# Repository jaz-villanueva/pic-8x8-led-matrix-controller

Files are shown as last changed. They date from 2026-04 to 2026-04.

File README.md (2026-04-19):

# PIC Ping Pong Game (8x8 LED Matrix)

## Overview
This project implements a two-player ping pong game using a PIC16F877A microcontroller and an 8x8 LED matrix driven by the MAX7219. The system displays the ball and paddles on the matrix, with button inputs controlling paddle movement.

The focus of this implementation is the **physical hardware realization**, including PCB assembly, soldering, and validation of a working embedded system.

---

## My Contribution
- Performed full hardware assembly and soldering of the PCB implementation
- Translated schematic and design into a working physical circuit
- Verified system operation through testing and debugging
- Ensured reliable hardware integration with the firmware and LED matrix display

---

## Inspiration
This project was inspired by the original implementation:
https://github.com/icelal-kskn/PicPong

The system design and firmware concept were adapted from this repository and used as a reference for building the hardware implementation.

---

## Features
- Two-player ping pong gameplay
- 8x8 LED matrix display output
- MAX7219-driven multiplexing
- Button-controlled paddle movement
- Real-time ball movement and collision detection

---

## Hardware Used
- PIC16F877A Microcontroller
- MAX7219 LED Driver
- 8x8 LED Matrix Display
- Push Buttons (Player Controls)
- Resistors and Capacitors
- Crystal Oscillator
- 5V Power Supply

---

## Software Used
- MikroC PRO for PIC (Firmware Development)
- Proteus (Simulation)
- KiCad (PCB Design)

---

## Hardware Implementation
This project emphasizes the **physical construction of the system**, including:
- PCB assembly and soldering
- Component placement and wiring
- Ensuring clean and reliable solder joints
- Validating circuit behavior with firmware

---

## Build Output
(Add your images here)

PCB
Working Output
Soldering

---

## Documentation
📄 [Project Report](docs/pic-ping-pong-game-report.pdf)

---

## Attribution
This project is based on the following open-source implementation:
https://github.com/icelal-kskn/PicPong

The original work is licensed under the MIT License. This repository uses that work in accordance with its license.

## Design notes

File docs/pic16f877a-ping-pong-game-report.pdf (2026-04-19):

## De La Salle University- Manila Gokongwei College of Engineering

Project Number | : 2
Project Title | : Ping Pong Game
Date Performed | : 4/14/2026
Date Submitted | : 4/14/2026
Instructor | : Dr. Argel A. Bandala
Name of Student | :
- Galvez, Ron John B.
- Metrillo, Brian David
- Romero, John Mark
- Villanueva, Jaz V.
Student ID | :
- 12334731
- 12300160
- 12313726
- 12314536
Subject / Section : LBYCPM3

## Objectives

- Design and implement a ping pong game using PIC16F877A microcontroller
- Develop a schematic diagram of the ping pong system
- Create and compile a working MikroC code for the PIC microcontroller
- Simulate the circuit using Proteus 8.11
- Develop a PCB design in KiCad based on schematic diagram

## Introductory Information

This project focuses on designing and building physical hardware for a ping pong game using a PIC16F877A 8-bit microcontroller. PIC16F877A was utilized for this project for the microcontroller supports enough I/O pins and memory for implementing basic systems such as this pong game system [1]. To create and compile the working code for the PIC microcontroller, the MikroC environment is utilized [2].

The game will utilize an 8x8 matrix LED display for outputting the ball and platform which is interfaced through a MAX7219 chip. The MAX7219 handles the multiplexing for the LEDs [3], and is interfaced to the PIC microcontroller using Serial Peripheral Interface (SPI) protocol that involves five connections namely VCC, GND, DIN, CS (LOAD), and CLK. These pin connections play a crucial role in making the PIC communicate with the matrix display.

For the inputs of the game, 6mm buttons are utilized so the players can control the movement of their platforms. The system accounts for debouncing to make sure the microcontroller does not register unintended multiple presses from the physical buttons.

Furthermore, the project involves simulating the circuit using Proteus 8.11 to check if the schematic diagram and code are working [4]. After a successful simulation, a PCB design is developed in KiCad based on the schematic diagram to complete the hardware implementation [5].

## Materials Needed:

- 1x 8x8 Matrix Display
- 1x MAX7219 Driver
- 5x 10 kiloohm resistor
- 1x PIC16F877A
- 1x PICKit2 with USB Cable
- Computer with PICKit2 programmer and MikroC
- 5x 6mm buttons
- Solid core wires/jumper wires
- 5V DC Power Supply

- 1x 16MHz Crystal Oscillator
- 2x 22pF capacitor

## Procedure

1. Circuit Design and Simulation in Proteus
a. Open Proteus and create a new schematic project.
b. Add the PIC16F877A from the component library and attach an 8 MHz crystal oscillator to the OSC1 and OSC2 pins, with two 22 pF capacitors to ground.
c. Add a MAX7219 LED driver and an 8x8 LED matrix display. Connect the DIN pin of the MAX7219 to RC5 (SDO), the CLK pin to RC3 (SCK), and the CS pin to RC0 of the PIC.
d. Connect the four player buttons to RB0, RB1, RB2, and RB3. Each button should have a 10 kilohm pull-down resistor to ground so that the pin reads low when the button is not pressed and high when it is pressed.
e. Connect a reset button (MCLR) to the MCLR/Vpp pin with a 10 kilohm pull-up resistor to VDD.
f. Add a 5V power supply to VDD and connect all VSS pins to ground.
g. Verify all schematic connections and save the Proteus project.
2. Firmware Development in MikroC
a. Open MikroC Pro for PIC and create a new project. Set the device to PIC16F877A and the oscillator to 8 MHz.
b. Write the MAX7219 initialization function (MAX7219_Init) to configure RC0 as the CS pin output and set up hardware SPI using SPI1_Init_Advanced with master mode, 16 clock divisor, idle low, and low-to-high clock edge.
c. Write MAX7219_Config to send the startup register values: disable decode mode, set intensity to mid-level (0x08), enable all 8 scan digits, turn off display test, and set normal operation mode.
d. Write MAX7219_Send to handle a single SPI register write: pull CS low, send the register address and data bytes, then pull CS high.
e. Define the five paddle states as bitmasks (STATE_1 through STATE_5), each representing a 4-row window of the 8-row matrix that shifts up or down in response to button presses.
f. Write ButtonGoUp and ButtonGoDown to handle paddle movement using a switch-case on the current paddle state, clamping at the top and bottom limits.
g. Write UpdateBallPosition to check for paddle collisions by ANDing the ball's current row bitmask against the paddle state at the matching column. If there is a hit, reverse ballDirX. Then advance the ball one step in both X and Y directions, bouncing the Y direction when the ball reaches row 0 or row 7. Set isScore to true if the ball exits the board at column 1 or column 8.
h. Write RenderFrame to clear all columns, then draw the paddles and the ball. If the ball is on the same column as a paddle, OR its bitmask into the paddle's row value before sending to the MAX7219.

i. Write InitGame to reset both paddles to STATE_3, reset ball position and direction, clear isScore, and call RenderFrame.
j. Write the main loop. After initialization, call InitGame then enter the inner game loop. Each iteration calls UpdateBallPosition, then runs a 1000 ms inner timing loop that reads and debounces all four buttons using edge detection against previous button states. Each inner iteration delays 8 ms and increments the elapsed counter. When isScore becomes true, exit the inner loop, wait 250 ms, and restart the game with InitGame.
k. Compile the firmware in MikroC. Fix any errors and recompile until a valid .hex file is produced.
3. Simulation and Testing
a. Load the .hex file into the PIC component in Proteus by double-clicking the component and pointing to the compiled .hex file path.
b. Run the simulation and confirm that both paddles appear centered on their respective columns (column 7 for Player 1, column 2 for Player 2) and that the ball starts moving.
c. Test paddle movement by pressing the buttons for Player 1 and Player 2. Confirm that each paddle shifts up or down on the matrix and stops at the edges.
d. Let the ball travel toward a paddle and confirm it bounces back when it hits. Let it past the paddle and confirm the game resets after a brief pause.
e. Take screenshots of the simulation for documentation.
4. PCB Schematic in KiCad
a. Open KiCad and create a new project. Open the schematic editor and place all components: the PIC16F877A, the 5-pin SPI connector (J3) for the MAX7219 module, the 2-pin power connector (J2), the four player buttons (SW1 to SW4) with their 10 kilohm pull-down resistors (R2 to R5), the MCLR reset button (SW5) with pull-up resistor (R1), and the 8 MHz crystal (Y1) with its two 22 pF load capacitors (C3 and C5).
b. Wire all nets following the same topology as the Proteus schematic. Connect the SPI lines (RC3, RC4, RC5) and CS (RC0) to the 5-pin connector. Connect the button pins to RB0 through RB3.
c. Run the electrical rules check (ERC) and fix any flagged issues before proceeding.
d. Open the PCB editor and import the netlist. Arrange components in a compact layout. Route all traces, keeping the SPI lines short and grouping the button resistors near their respective switches.
e. Run the design rules check (DRC) to confirm no clearance violations.
f. Export the schematic and PCB screenshots for documentation.
5. Physical Implementation
a. Assemble the circuit on a breadboard following the KiCad schematic.
b. Connect the PIC16F877A, crystal, capacitors, and MCLR button first. Then wire the buttons and pull-down resistors to PORTB.

c. Connect the SPI lines from PORTC to the MAX7219 module and then connect the 8x8 LED matrix to the MAX7219 outputs.
d. Supply 5V DC power to the circuit.
e. Flash the compiled .hex file to the PIC using PICKit2 and the MikroC programmer tool.
f. Power on the circuit and verify that the game runs correctly. Test both paddles and confirm the ball bounces and the game resets on a score.
g. Once breadboard version works, transfer everything to a universal PCB via soldering. Refer to traces made in KiCad PCB layout. Repeat steps B to F on the universal PCB.
h. Take photos of the working physical implementation for documentation.

## Firmware Flowchart

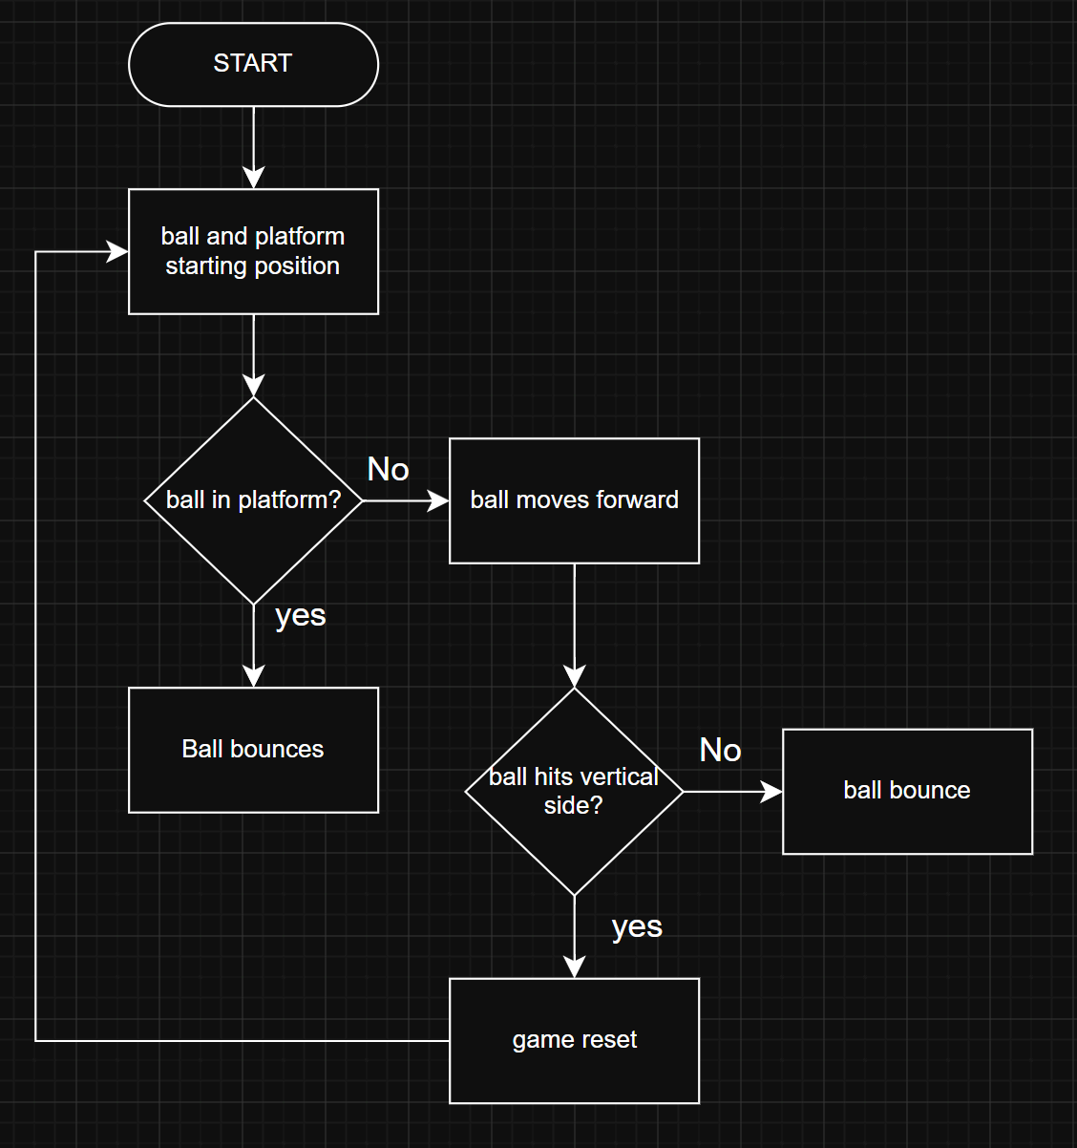
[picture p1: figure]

## Data and Results

Proteus Schematic

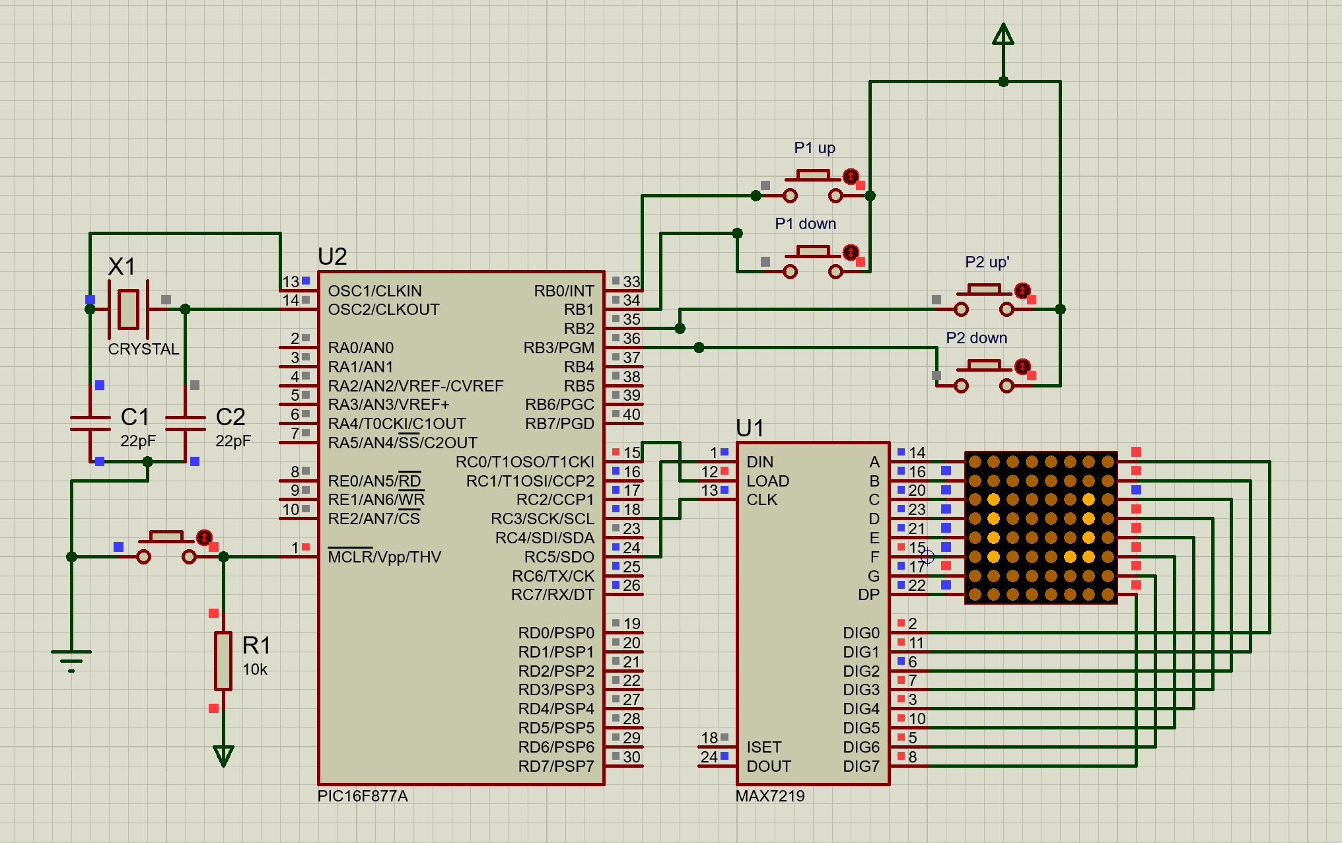
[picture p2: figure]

Physical Implementation

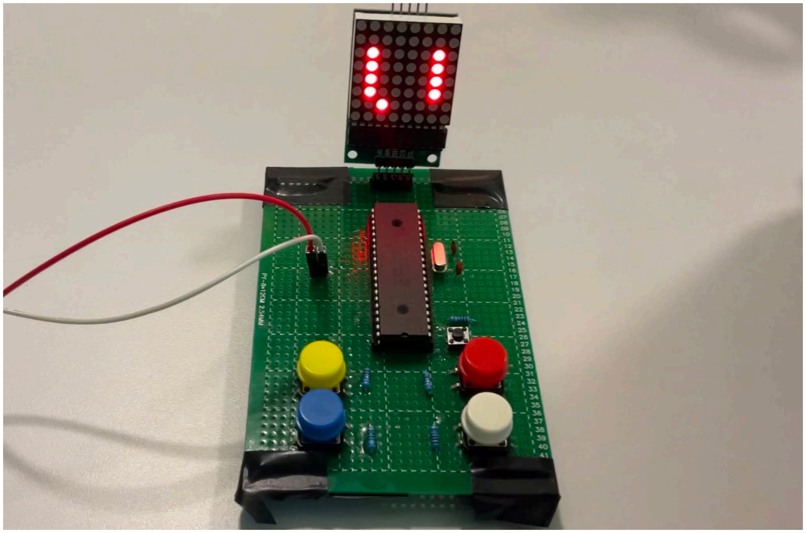
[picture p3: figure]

Video Demonstration:
https://drive.google.com/file/d/1vLUG_qZoW9VsrUOYHv4MvmWK9TPfnm_L/view?usp=drivesd k (https://drive.google.com/file/d/1vLUG_qZoW9VsrUOYHv4MvmWK9TPfnm_L/view?usp=drivesdk)

KiCad Schematic

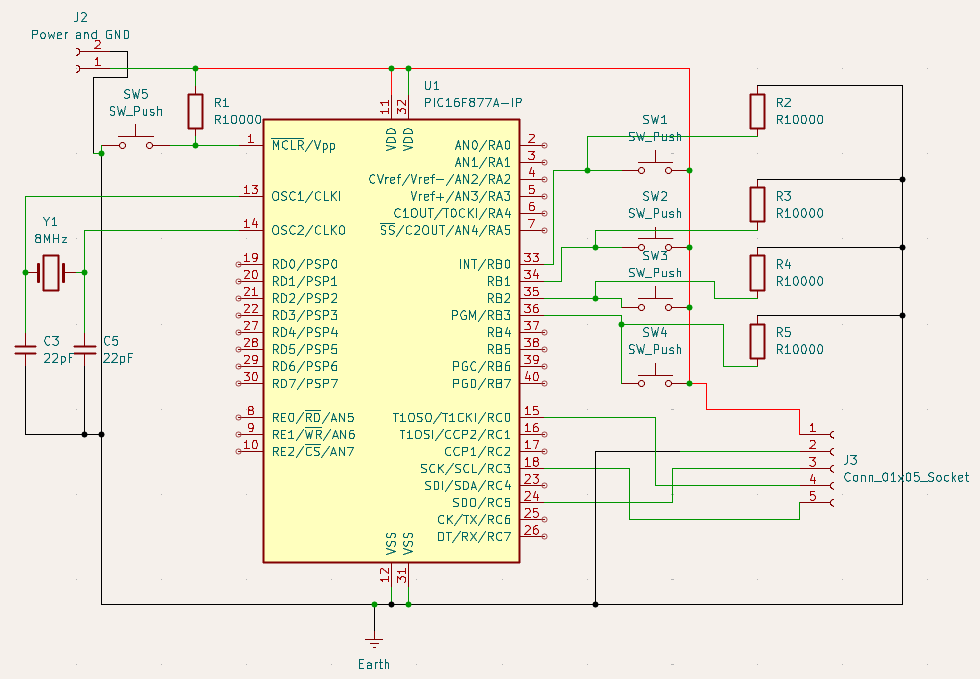
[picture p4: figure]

KiCad PCB Design

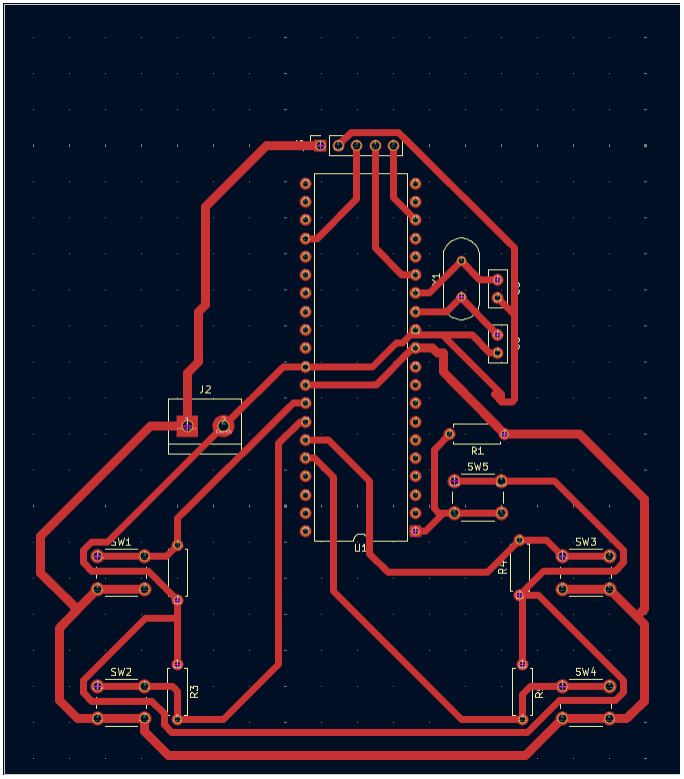
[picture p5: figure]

MikroC Code

/*

* File: PONG_PROJ.c

* Pong Game - PIC16F877A + MAX7219 8x8 LED Matrix

* MikroC Pro for PIC

*

* Wiring (Hardware SPI):

* RC5/SDO -> DIN

* RC3/SCK -> CLK

* RC0 | -> CS
* RB0 | -> Player 1 Up (Active High)
* RB1 | -> Player 1 Down (Active High)
* RB2 | -> Player 2 Up (Active High)
* RB3 | -> Player 2 Down (Active High)

*/

// ===================== Bool ===============================================

#define bool unsigned char

#define true 1

#define false 0

// ===================== Button Pins ========================================

#define Player1_up_pin RB3_bit

#define Player1_down_pin RB2_bit

#define Player2_up_pin RB1_bit

#define Player2_down_pin RB0_bit

#define BUTTON_PRESSED(pin) ((pin) == 1)

// ===================== MAX7219 Register Addresses =========================

#define NO_OP_REG | 0x00

#define DECODE_MODE_REG | 0x09

#define INTENSITY_REG | 0x0A

#define SCAN_LIMIT_REG | 0x0B

#define SHUTDOWN_REG | 0x0C

#define DISPLAY_TEST_REG 0x0F

// ===================== MAX7219 Configuration Values =======================

#define DISABLE_DECODE | 0x00

#define BRIGHTNESS | 0x08

#define SCAN_ALL_DIGITS | 0x07

#define NORMAL_OPERATION 0x01

#define DISABLE_TEST 0x00

// ===================== MAX7219 CS Pin ====================================

#define MAX7219_CS RC0_bit

#define MAX7219_CS_DIR TRISC0_bit

// ===================== Board / Timing =====================================

#define PLAYER1_COL 7

#define PLAYER2_COL | 2

#define FRAME_DELAY_MS | 1000

#define DEBOUNCE_DELAY_MS 8

// ===================== LED Row Bitmasks ===================================

#define No_Light 0x00

#define Row0 | 0x01

#define Row1 | 0x02

#define Row2 | 0x04

#define Row3 | 0x08

#define Row4 | 0x10

#define Row5 | 0x20

#define Row6 | 0x40

#define Row7 | 0x80

// ===================== Paddle States (4-row paddle) =======================

#define STATE_5 0xF0

#define STATE_4 0x78

#define STATE_3 0x3C

#define STATE_2 0x1E

#define STATE_1 0x0F

// ===================== Global Game Variables ==============================

unsigned char p1State = STATE_3;

unsigned char p2State = STATE_3;

int ballDirX = -1;

int ballDirY = 1;

int ballX = 4;

unsigned char ballYState = Row4;

bool isScore = false;

unsigned char prevB0 = 0;

unsigned char prevB1 = 0;

unsigned char prevB2 = 0;

unsigned char prevB3 = 0;

// ===================== MAX7219 Low-Level ==================================

void MAX7219_Send(unsigned char regAddr, unsigned char regData) {

MAX7219_CS = 0;

SPI1_Write(regAddr);

SPI1_Write(regData);

MAX7219_CS = 1;

}

void MAX7219_Clear() {

unsigned char col;

for (col = 1; col <= 8; col++) {

MAX7219_Send(col, No_Light);

}

}

void MAX7219_Config() {

MAX7219_Send(DISPLAY_TEST_REG, DISABLE_TEST);

MAX7219_Send(SHUTDOWN_REG, NORMAL_OPERATION);

MAX7219_Send(DECODE_MODE_REG, DISABLE_DECODE);

MAX7219_Send(INTENSITY_REG, BRIGHTNESS);

MAX7219_Send(SCAN_LIMIT_REG, SCAN_ALL_DIGITS);

}

void MAX7219_Init() {

MAX7219_CS_DIR = 0;

MAX7219_CS = 1;

TRISC3_bit = 0; // SCK output

TRISC5_bit = 0; // SDO output

RC3_bit = 0;

RC5_bit = 0;

SPI1_Init_Advanced(

_SPI_MASTER_OSC_DIV16,

_SPI_DATA_SAMPLE_MIDDLE,

_SPI_CLK_IDLE_LOW,

_SPI_LOW_2_HIGH

);

}

// ===================== Game Display =======================================

void ApplyPaddleState(unsigned char playerCol, unsigned char paddleState) {

MAX7219_Send(playerCol, paddleState);

}

void RenderFrame() {

unsigned char col;

unsigned char p1Render;

unsigned char p2Render;

for (col = 1; col <= 8; col++) {

MAX7219_Send(col, No_Light);

}

p1Render = p1State;

p2Render = p2State;

if (ballX == PLAYER1_COL) p1Render |= ballYState;

if (ballX == PLAYER2_COL) p2Render |= ballYState;

ApplyPaddleState(PLAYER1_COL, p1Render);

ApplyPaddleState(PLAYER2_COL, p2Render);

if ((ballX != PLAYER1_COL) && (ballX != PLAYER2_COL)) {

MAX7219_Send((unsigned char)ballX, ballYState);

}

}

void InitGame() {

p1State = STATE_3;

p2State = STATE_3;

ballX = 5;

ballYState = Row4;

ballDirX = -1;

ballDirY = 1;

isScore = false;

MAX7219_Clear();

RenderFrame();

}

// ===================== Button Reading =====================================

unsigned char ReadButton0() { return BUTTON_PRESSED(Player1_up_pin); }

unsigned char ReadButton1() { return BUTTON_PRESSED(Player1_down_pin); }

unsigned char ReadButton2() { return BUTTON_PRESSED(Player2_up_pin); }

unsigned char ReadButton3() { return BUTTON_PRESSED(Player2_down_pin); }

// ===================== Paddle Movement ====================================

void ButtonGoUp(unsigned char player) {

if (player == 1) {

switch (p1State) {

case STATE_1: p1State = STATE_2; break;

case STATE_2: p1State = STATE_3; break;

case STATE_3: p1State = STATE_4; break;

case STATE_4: p1State = STATE_5; break;

case STATE_5: p1State = STATE_5; break;

default: p1State = STATE_3; break;

}

} else {

switch (p2State) {

case STATE_1: p2State = STATE_2; break;

case STATE_2: p2State = STATE_3; break;

case STATE_3: p2State = STATE_4; break;

case STATE_4: p2State = STATE_5; break;

case STATE_5: p2State = STATE_5; break;

default: p2State = STATE_3; break;

}

}

}

void ButtonGoDown(unsigned char player) {

if (player == 1) {

switch (p1State) {

case STATE_1: p1State = STATE_1; break;

case STATE_2: p1State = STATE_1; break;

case STATE_3: p1State = STATE_2; break;

case STATE_4: p1State = STATE_3; break;

case STATE_5: p1State = STATE_4; break;

default: p1State = STATE_3; break;

}

} else {

switch (p2State) {

case STATE_1: p2State = STATE_1; break;

case STATE_2: p2State = STATE_1; break;

case STATE_3: p2State = STATE_2; break;

case STATE_4: p2State = STATE_3; break;

case STATE_5: p2State = STATE_4; break;

default: p2State = STATE_3; break;

}

}

}

// ===================== Ball Logic =========================================

void UpdateBallPosition() {

if (ballX == PLAYER2_COL) {

if (p2State & ballYState) {

ballDirX = -ballDirX;

}

} else if (ballX == PLAYER1_COL) {

if (p1State & ballYState) {

ballDirX = -ballDirX;

}

}

ballX += ballDirX;

if ((ballYState & Row0) == Row0) {

ballYState = Row1;

ballDirY = 1;

} else if ((ballYState & Row1) == Row1) {

ballYState = (ballDirY == 1) ? Row2 : Row0;

} else if ((ballYState & Row2) == Row2) {

ballYState = (ballDirY == 1) ? Row3 : Row1;

} else if ((ballYState & Row3) == Row3) {

ballYState = (ballDirY == 1) ? Row4 : Row2;

} else if ((ballYState & Row4) == Row4) {

ballYState = (ballDirY == 1) ? Row5 : Row3;

} else if ((ballYState & Row5) == Row5) {

ballYState = (ballDirY == 1) ? Row6 : Row4;

} else if ((ballYState & Row6) == Row6) {

ballYState = (ballDirY == 1) ? Row7 : Row5;

} else if ((ballYState & Row7) == Row7) {

ballYState = Row6;

ballDirY = -1;

}

if ((ballX == 1) || (ballX == 8)) {

isScore = true;

}

RenderFrame();

}

// ===================== Main ===============================================

void main() {

unsigned int elapsed;

unsigned char b0, b1, b2, b3;

TRISB = 0xFF;

TRISC = 0x00;

PORTB = 0x00;

PORTC = 0x00;

OPTION_REG |= 0x80; // disable PORTB pull-ups

MAX7219_Init();

MAX7219_Config();

while (1) {

InitGame();

while (!isScore) {

elapsed = 0;

UpdateBallPosition();

while (elapsed < FRAME_DELAY_MS) {

b0 = ReadButton0();

b1 = ReadButton1();

b2 = ReadButton2();

b3 = ReadButton3();

if (b0 && !prevB0) {

ButtonGoUp(1);

RenderFrame();

}

if (b1 && !prevB1) {

ButtonGoDown(1);

RenderFrame();

}

if (b2 && !prevB2) {

ButtonGoUp(2);

RenderFrame();

}

if (b3 && !prevB3) {

ButtonGoDown(2);

RenderFrame();

}

prevB0 = b0;

prevB1 = b1;

prevB2 = b2;

prevB3 = b3;

Delay_ms(DEBOUNCE_DELAY_MS);

elapsed += DEBOUNCE_DELAY_MS;

}

}

Delay_ms(250);

}

}

C/C++

C/C++

## Discussion

Our project is a two-player pong game built on the PIC16F877A microcontroller, using a MAX7219 LED driver to control an 8x8 LED matrix as the display. Player 1 controls the right paddle at column 7 using RB3 (up) and RB2 (down), while Player 2 controls the left paddle at column 2 using RB1 (up) and RB0 (down). The ball moves diagonally across the matrix, bouncing off the top and bottom edges and reversing direction when it hits a paddle. If the ball passes a paddle and exits the board, the game resets.
To drive the 8x8 matrix, we used the MAX7219, a serial LED driver that handles all the row scanning internally. It communicates with the PIC over hardware SPI on the PORTC pins, which keeps the firmware simple since we only need to write a column register value to update that column on the display. The CS pin (RC0) is manually toggled before and after each SPI transfer:

void MAX7219_Send(unsigned char regAddr, unsigned char regData) { MAX7219_CS = 0;
SPI1_Write(regAddr);
SPI1_Write(regData);
MAX7219_CS = 1;
}

We configured the MAX7219 on startup to disable BCD decode mode (since we are directly writing bitmasks), set a medium brightness, and enable all 8 rows via the scan limit register. This only needs to be done once in MAX7219_Config during initialization.

Each paddle is stored as a single byte bitmask representing which of the 8 rows in its column are lit. Since the paddle covers 4 rows at a time, there are exactly 5 valid positions it can be in:

STATE_1 = 0x0F (rows 0-3, bottom of matrix) STATE_2 = 0x1E (rows 1-4)
STATE_3 = 0x3C (rows 2-5, center)
STATE_4 = 0x78 (rows 3-6)
STATE_5 = 0xF0 (rows 4-7, top of matrix)

Moving the paddle up or down just transitions between these states using a switch-case. The paddle is clamped at STATE_1 and STATE_5 so it cannot go off screen. Both paddles start at STATE_3 at the center.

C/C++

C/C++

C/C++

This bitmask approach is what makes collision detection straightforward. To check if the ball hit a paddle, we just AND the ball's row bitmask against the paddle's current state:

if (p1State & ballYState) {
ballDirX = -ballDirX;
}

If the result is nonzero, the ball is on a row that the paddle occupies, so we reverse the horizontal direction.
The ball's horizontal position is tracked as an integer column (ballX), and its vertical position is tracked as a row bitmask (ballYState) using the same Row0 through Row7 definitions used for the paddles. Each call to UpdateBallPosition checks for paddle collisions, then moves the ball by adding ballDirX to ballX and shifting ballYState in the direction of ballDirY. When the ball reaches Row0 or Row7, the vertical direction is reversed:

} else if ((ballYState & Row7) == Row7) { ballYState = Row6;
ballDirY = -1;
}

If ballX goes to 1 or 8, the ball has left the playfield and isScore is set to true, ending the round.
Instead of using timer interrupts, the game uses a simple polling loop with Delay_ms for timing. Each frame, UpdateBallPosition is called once to move the ball, then a 1000 ms inner loop runs in 8 ms steps. During each step, all four buttons are read and checked for rising edges using edge detection against the previous button state:

if (b0 && !prevB0) {
ButtonGoUp(1);
RenderFrame();
}

The 8 ms delay between reads also acts as a basic software debounce, which is the same approach used in Project 1. The edge detection (comparing current state to the previous state) ensures that a held button only registers one press per frame cycle.

C/C++

This approach is simpler than interrupt-driven input but has one tradeoff: the ball speed is fixed at roughly one move per second and cannot be changed without adjusting FRAME_DELAY_MS. The button polling is responsive enough within each frame because the inner loop runs 125 iterations in one second (1000 ms / 8 ms), so button presses are detected quickly.
The RenderFrame function clears all 8 columns first by writing 0x00 to each, then redraws the paddles and the ball. One edge case that needed handling is when the ball is on the same column as a paddle. In that case, the ball's row bitmask is OR'd into the paddle's state before sending to the MAX7219, so both the paddle and the ball are visible on that column at the same time:

if (ballX == PLAYER1_COL) p1Render |= ballYState;

This prevents the ball from being invisible when it is directly on a paddle column, which would make the collision harder to see visually.
Overall, the game worked correctly in simulation and on the actual hardware. One thing we noticed is that the fixed 1-second frame delay makes the game feel quite slow. A shorter delay, maybe 200 to 300 ms, would make it more playable. The game also does not distinguish which player scored, it just resets. Adding a score counter displayed before each round, or using the LED matrix to flash a short pattern, would make the game more complete. The PCB layout was also a bit large due to the button placement around the board edges, but it kept the routing clean without any overlapping traces.

## Analysis and conclusion

The ping pong game system was successfully implemented using the PIC16F877A microcontroller, MAX7219 LED driver, and an 8x8 LED matrix display. Based on the simulation in Proteus, the prototyped PCB in KiCad, and the actual hardware output shown in the results section, the system behaves as expected. The paddles respond correctly to the button inputs, the ball moves consistently across the matrix, and collisions with paddles and boundaries are properly detected.

One of the strengths of the system is using MAX7219 for driving the LED matrix. Since the driver handles multiplexing internally, the microcontroller only needs to send simple SPI commands, which makes the firmware easier to manage. The use of bitmasks for representing both the paddles and the ball also made the implementation more efficient. This helped us simplify rendering and allowed collision detection to be done using basic logical operations, which is good for a microcontroller with limited resources.

The button handling also worked reliably due to the combination of edge detection and a small delay for debouncing. This ensured that each press is only registered once per cycle, preventing unintended multiple movements. As a result, the controls feel consistent during gameplay.

However, some limitations were observed. The most noticeable issue is the slow game speed caused by the fixed 1000 ms frame delay. While this makes the timing easier to implement using a polling loop, it also makes the game less engaging. Reducing this delay or using a timer-based approach could improve responsiveness. Another limitation is that the system does not track or display scores. The game simply resets when the ball exits the playfield, which makes it feel incomplete. Additionally, the PCB layout is functional but relatively large, suggesting that component placement can still be optimized.

Overall, the project met all the stated objectives, including designing the circuit, developing the firmware, simulating the system, and implementing it on actual hardware. The system demonstrates proper integration of hardware and software components and shows a clear understanding of microcontroller-based design. While there are areas for improvement, the current implementation is stable and functional, and it provides a solid foundation for further enhancements.

## References

[1] Microchip Technology, "PIC16F87XA Data Sheet," Microchip Technology Inc., 2003. [Online]. Available: https://ww1.microchip.com/downloads/en/DeviceDoc/39582b.pdf
[2] MikroElektronika, "MikroC PRO for PIC - User Manual," MikroElektronika, 2011. [Online]. Available:
https://download.mikroe.com/documents/compilers/mikroc/pic/mikroc-pic-manual-v701.pdf

[3] Analog Devices, "MAX7219/MAX7221 Serially Interfaced, 8-Digit LED Display Drivers," Rev. 4, Analog Devices Inc., 2003. [Online]. Available: https://www.analog.com/media/en/technical-documentation/data-sheets/MAX7219-MAX7221.pd f (https://www.analog.com/media/en/technical-documentation/data-sheets/MAX7219-MAX7221.pdf)
[4] Labcenter Electronics, "Proteus Design Suite User Manual," Labcenter Electronics Ltd. [Online]. Available: https://www.labcenter.com/
[5] KiCad Developers Team, "KiCad Documentation," KiCad EDA. [Online]. Available: https://docs.kicad.org/

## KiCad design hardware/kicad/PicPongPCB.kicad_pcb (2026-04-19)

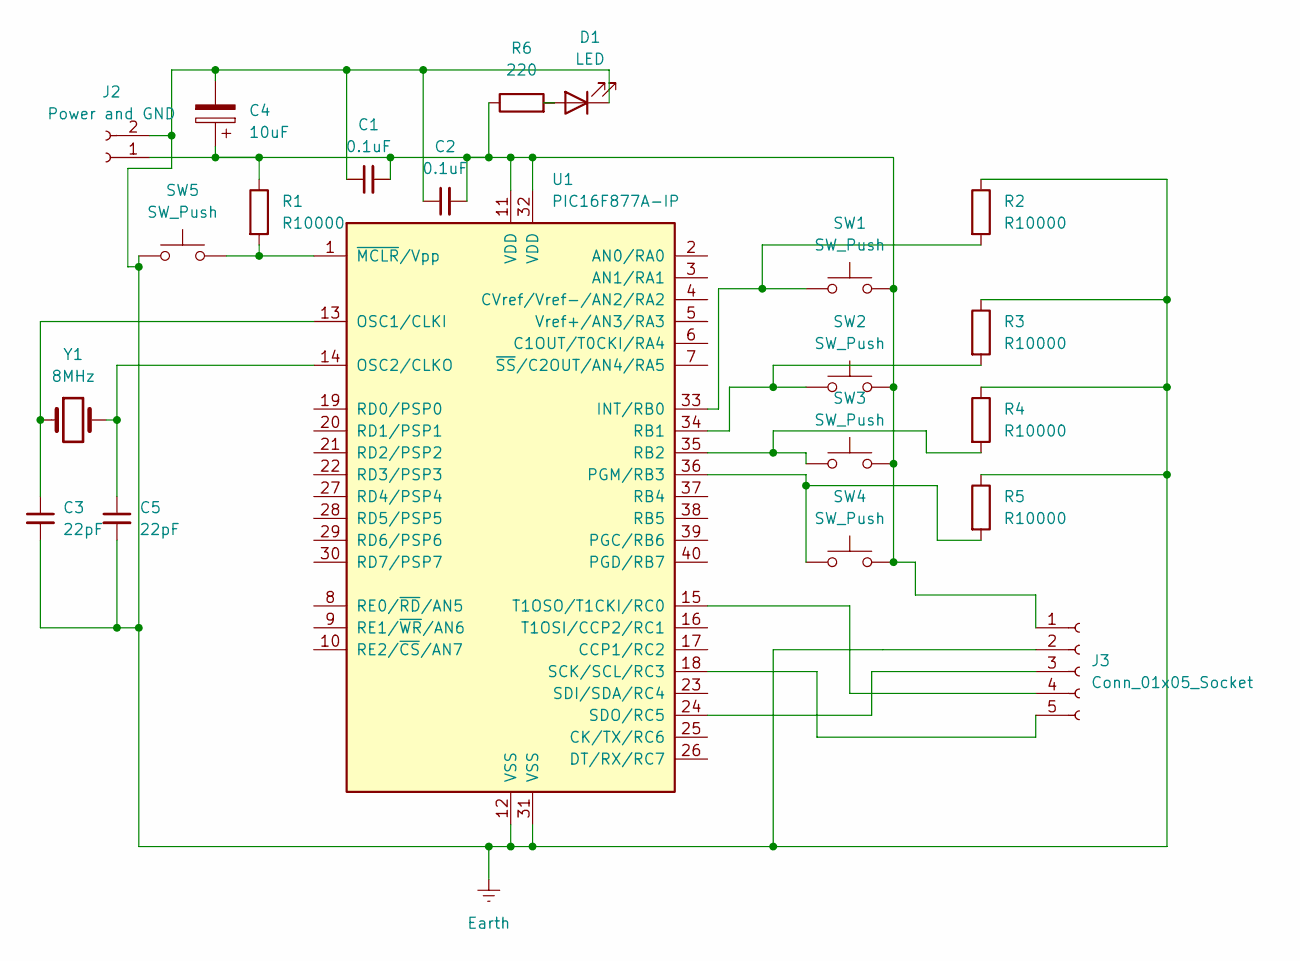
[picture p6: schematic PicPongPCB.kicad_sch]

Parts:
C1, C2: 0.1uF; C_Disc_D5.0mm_W2.5mm_P2.50mm
C3, C5: 22pF; C_Disc_D5.0mm_W2.5mm_P2.50mm
C4: 10uF; CP_Radial_D4.0mm_P2.00mm
D1: LED; LED_D3.0mm
J2: Power and GND; TerminalBlock_bornier-2_P5.08mm
J3: Conn_01x05_Socket; PinSocket_1x05_P2.54mm_Vertical
R1, R2, R3, R4, R5: R10000; R_Axial_DIN0207_L6.3mm_D2.5mm_P7.62mm_Horizontal
R6: 220; R_Axial_DIN0207_L6.3mm_D2.5mm_P7.62mm_Horizontal
SW1, SW2, SW3, SW4, SW5: SW_Push; SW_PUSH_6mm_H5mm
U1: PIC16F877A-IP; DIP-40_W15.24mm
Y1: 8MHz; Crystal_HC49-U_Vertical

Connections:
Earth: C1.1, C2.1, C3.2, C4.2, C5.2, D1.1 (K), J2.2, J3.2, R2.1, R3.1, R4.1, R5.1, SW5.1, U1.12 (VSS), U1.31 (VSS)
unnamed: D1.2 (A), R6.2
unnamed: C1.2, C2.2, C4.1, J2.1, J3.1, R1.1, R6.1, SW1.2, SW2.2, SW3.2, SW4.2, U1.11 (VDD), U1.32 (VDD)
unnamed: J3.3, U1.24 (SDO/RC5)
unnamed: J3.4, U1.15 (T1OSO/T1CKI/RC0)
unnamed: J3.5, U1.18 (SCK/SCL/RC3)
unnamed: R2.2, SW1.1, U1.33 (INT/RB0)
unnamed: C3.1, U1.13 (OSC1/CLKI), Y1.1
unnamed: C5.1, U1.14 (OSC2/CLKO), Y1.2
unnamed: R5.2, SW4.1, U1.36 (PGM/RB3)
unnamed: R3.2, SW2.1, U1.34 (RB1)
unnamed: R4.2, SW3.1, U1.35 (RB2)
unnamed: R1.2, SW5.2, U1.1 (~MCLR/Vpp)

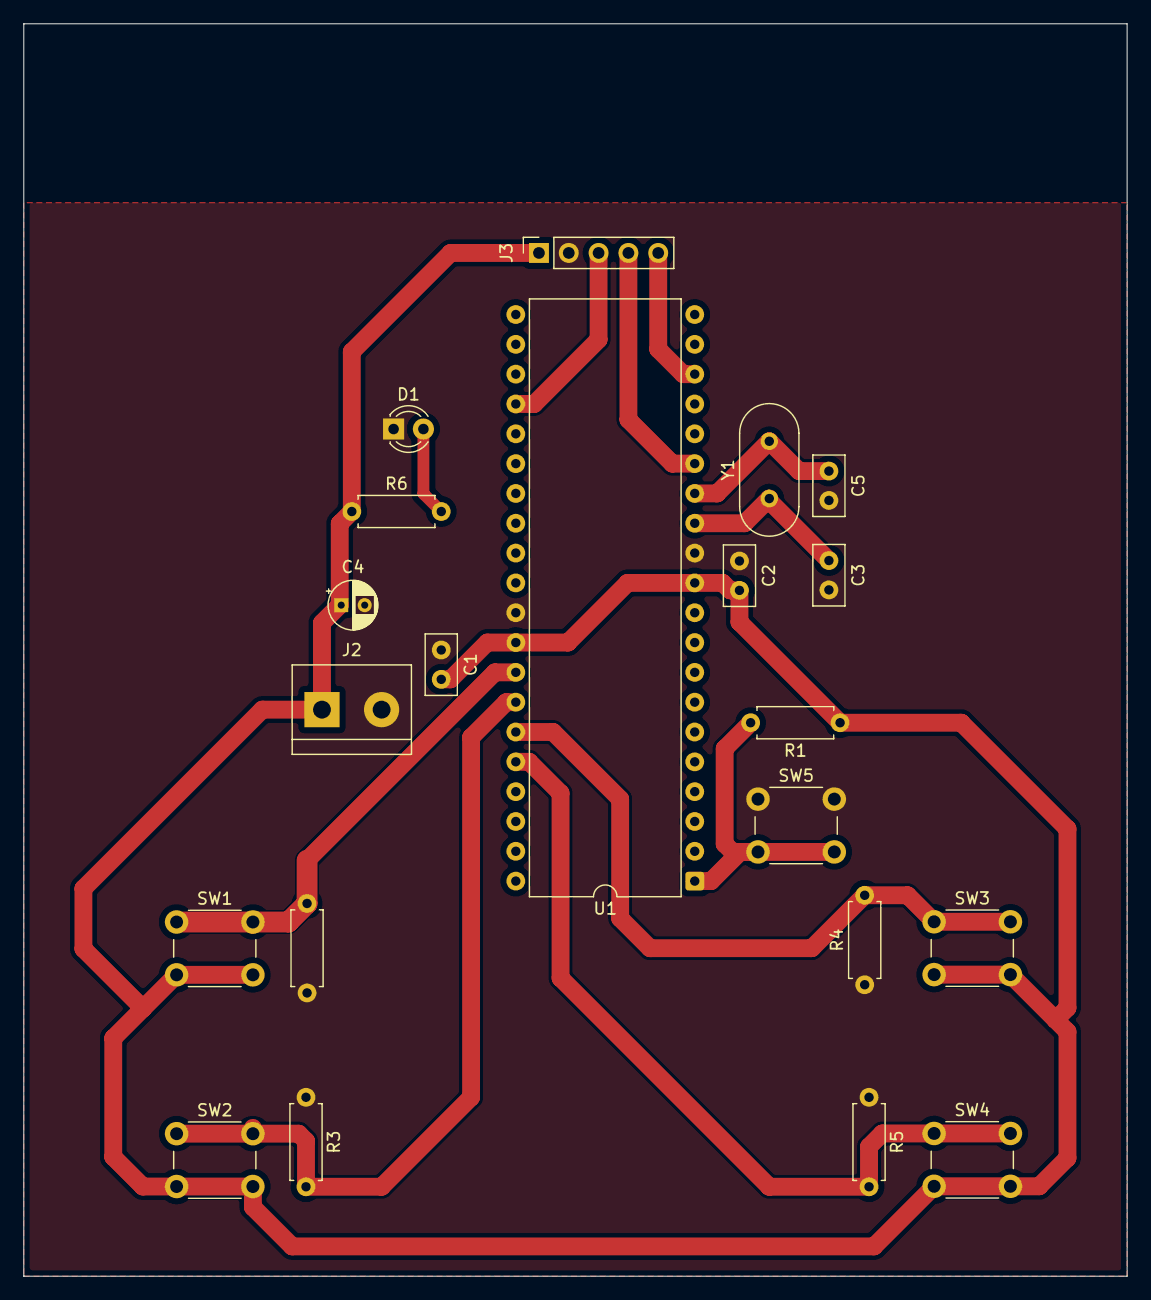
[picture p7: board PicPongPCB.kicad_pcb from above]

Board: 2 copper layers, 94.0 x 106.7 mm, 21 parts (0 on the bottom side), 13 nets.

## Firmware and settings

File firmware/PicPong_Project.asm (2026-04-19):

_MAX7219_Send:

;PicPong_Project.c,89 :: 		void MAX7219_Send(unsigned char regAddr, unsigned char regData) {
;PicPong_Project.c,90 :: 		MAX7219_CS = 0;
	BCF        RC0_bit+0, BitPos(RC0_bit+0)
;PicPong_Project.c,91 :: 		SPI1_Write(regAddr);
	MOVF       FARG_MAX7219_Send_regAddr+0, 0
	MOVWF      FARG_SPI1_Write_data_+0
	CALL       _SPI1_Write+0
;PicPong_Project.c,92 :: 		SPI1_Write(regData);
	MOVF       FARG_MAX7219_Send_regData+0, 0
	MOVWF      FARG_SPI1_Write_data_+0
	CALL       _SPI1_Write+0
;PicPong_Project.c,93 :: 		MAX7219_CS = 1;
	BSF        RC0_bit+0, BitPos(RC0_bit+0)
;PicPong_Project.c,94 :: 		}
L_end_MAX7219_Send:
	RETURN
; end of _MAX7219_Send

_MAX7219_Clear:

;PicPong_Project.c,96 :: 		void MAX7219_Clear() {
;PicPong_Project.c,98 :: 		for (col = 1; col <= 8; col++) {
	MOVLW      1
	MOVWF      MAX7219_Clear_col_L0+0
L_MAX7219_Clear0:
	MOVF       MAX7219_Clear_col_L0+0, 0
	SUBLW      8
	BTFSS      STATUS+0, 0
	GOTO       L_MAX7219_Clear1
;PicPong_Project.c,99 :: 		MAX7219_Send(col, No_Light);
	MOVF       MAX7219_Clear_col_L0+0, 0
	MOVWF      FARG_MAX7219_Send_regAddr+0
	CLRF       FARG_MAX7219_Send_regData+0
	CALL       _MAX7219_Send+0
;PicPong_Project.c,98 :: 		for (col = 1; col <= 8; col++) {
	INCF       MAX7219_Clear_col_L0+0, 1
;PicPong_Project.c,100 :: 		}
	GOTO       L_MAX7219_Clear0
L_MAX7219_Clear1:
;PicPong_Project.c,101 :: 		}
L_end_MAX7219_Clear:
	RETURN
; end of _MAX7219_Clear

_MAX7219_Config:

;PicPong_Project.c,103 :: 		void MAX7219_Config() {
;PicPong_Project.c,104 :: 		MAX7219_Send(DISPLAY_TEST_REG, DISABLE_TEST);
	MOVLW      15
	MOVWF      FARG_MAX7219_Send_regAddr+0
	CLRF       FARG_MAX7219_Send_regData+0
	CALL       _MAX7219_Send+0
;PicPong_Project.c,105 :: 		MAX7219_Send(SHUTDOWN_REG, NORMAL_OPERATION);
	MOVLW      12
	MOVWF      FARG_MAX7219_Send_regAddr+0
	MOVLW      1
	MOVWF      FARG_MAX7219_Send_regData+0
	CALL       _MAX7219_Send+0
;PicPong_Project.c,106 :: 		MAX7219_Send(DECODE_MODE_REG, DISABLE_DECODE);
	MOVLW      9
	MOVWF      FARG_MAX7219_Send_regAddr+0
	CLRF       FARG_MAX7219_Send_regData+0
	CALL       _MAX7219_Send+0
;PicPong_Project.c,107 :: 		MAX7219_Send(INTENSITY_REG, BRIGHTNESS);
	MOVLW      10
	MOVWF      FARG_MAX7219_Send_regAddr+0
	MOVLW      8
	MOVWF      FARG_MAX7219_Send_regData+0
	CALL       _MAX7219_Send+0
;PicPong_Project.c,108 :: 		MAX7219_Send(SCAN_LIMIT_REG, SCAN_ALL_DIGITS);
	MOVLW      11
	MOVWF      FARG_MAX7219_Send_regAddr+0
	MOVLW      7
	MOVWF      FARG_MAX7219_Send_regData+0
	CALL       _MAX7219_Send+0
;PicPong_Project.c,109 :: 		}
L_end_MAX7219_Config:
	RETURN
; end of _MAX7219_Config

_MAX7219_Init:

;PicPong_Project.c,111 :: 		void MAX7219_Init() {
;PicPong_Project.c,112 :: 		MAX7219_CS_DIR = 0;
	BCF        TRISC0_bit+0, BitPos(TRISC0_bit+0)
;PicPong_Project.c,113 :: 		MAX7219_CS = 1;
	BSF        RC0_bit+0, BitPos(RC0_bit+0)
;PicPong_Project.c,115 :: 		TRISC3_bit = 0;   // SCK output
	BCF        TRISC3_bit+0, BitPos(TRISC3_bit+0)
;PicPong_Project.c,116 :: 		TRISC5_bit = 0;   // SDO output
	BCF        TRISC5_bit+0, BitPos(TRISC5_bit+0)
;PicPong_Project.c,118 :: 		RC3_bit = 0;
	BCF        RC3_bit+0, BitPos(RC3_bit+0)
;PicPong_Project.c,119 :: 		RC5_bit = 0;
	BCF        RC5_bit+0, BitPos(RC5_bit+0)
;PicPong_Project.c,122 :: 		_SPI_MASTER_OSC_DIV16,
	MOVLW      1
	MOVWF      FARG_SPI1_Init_Advanced_master+0
;PicPong_Project.c,123 :: 		_SPI_DATA_SAMPLE_MIDDLE,
	CLRF       FARG_SPI1_Init_Advanced_data_sample+0
;PicPong_Project.c,124 :: 		_SPI_CLK_IDLE_LOW,
	CLRF       FARG_SPI1_Init_Advanced_clock_idle+0
;PicPong_Project.c,125 :: 		_SPI_LOW_2_HIGH
	MOVLW      1
	MOVWF      FARG_SPI1_Init_Advanced_transmit_edge+0
	CALL       _SPI1_Init_Advanced+0
;PicPong_Project.c,127 :: 		}
L_end_MAX7219_Init:
	RETURN
; end of _MAX7219_Init

_ApplyPaddleState:

;PicPong_Project.c,130 :: 		void ApplyPaddleState(unsigned char playerCol, unsigned char paddleState) {
;PicPong_Project.c,131 :: 		MAX7219_Send(playerCol, paddleState);
	MOVF       FARG_ApplyPaddleState_playerCol+0, 0
	MOVWF      FARG_MAX7219_Send_regAddr+0
	MOVF       FARG_ApplyPaddleState_paddleState+0, 0
	MOVWF      FARG_MAX7219_Send_regData+0
	CALL       _MAX7219_Send+0
;PicPong_Project.c,132 :: 		}
L_end_ApplyPaddleState:
	RETURN
; end of _ApplyPaddleState

_RenderFrame:

;PicPong_Project.c,134 :: 		void RenderFrame() {
;PicPong_Project.c,139 :: 		for (col = 1; col <= 8; col++) {
	MOVLW      1
	MOVWF      RenderFrame_col_L0+0
L_RenderFrame3:
	MOVF       RenderFrame_col_L0+0, 0
	SUBLW      8
	BTFSS      STATUS+0, 0
	GOTO       L_RenderFrame4
;PicPong_Project.c,140 :: 		MAX7219_Send(col, No_Light);
	MOVF       RenderFrame_col_L0+0, 0
	MOVWF      FARG_MAX7219_Send_regAddr+0
	CLRF       FARG_MAX7219_Send_regData+0
	CALL       _MAX7219_Send+0
;PicPong_Project.c,139 :: 		for (col = 1; col <= 8; col++) {
	INCF       RenderFrame_col_L0+0, 1
;PicPong_Project.c,141 :: 		}
	GOTO       L_RenderFrame3
L_RenderFrame4:
;PicPong_Project.c,143 :: 		p1Render = p1State;
	MOVF       _p1State+0, 0
	MOVWF      RenderFrame_p1Render_L0+0
;PicPong_Project.c,144 :: 		p2Render = p2State;
	MOVF       _p2State+0, 0
	MOVWF      RenderFrame_p2Render_L0+0
;PicPong_Project.c,146 :: 		if (ballX == PLAYER1_COL) p1Render |= ballYState;
	MOVLW      0
	XORWF      _ballX+1, 0
	BTFSS      STATUS+0, 2
	GOTO       L__RenderFrame114
	MOVLW      7
	XORWF      _ballX+0, 0
L__RenderFrame114:
	BTFSS      STATUS+0, 2
	GOTO       L_RenderFrame6
	MOVF       _ballYState+0, 0
	IORWF      RenderFrame_p1Render_L0+0, 1
L_RenderFrame6:
;PicPong_Project.c,147 :: 		if (ballX == PLAYER2_COL) p2Render |= ballYState;
	MOVLW      0
	XORWF      _ballX+1, 0
	BTFSS      STATUS+0, 2
	GOTO       L__RenderFrame115
	MOVLW      2
	XORWF      _ballX+0, 0
L__RenderFrame115:
	BTFSS      STATUS+0, 2
	GOTO       L_RenderFrame7
	MOVF       _ballYState+0, 0
	IORWF      RenderFrame_p2Render_L0+0, 1
L_RenderFrame7:
;PicPong_Project.c,149 :: 		ApplyPaddleState(PLAYER1_COL, p1Render);
	MOVLW      7
	MOVWF      FARG_ApplyPaddleState_playerCol+0
	MOVF       RenderFrame_p1Render_L0+0, 0
	MOVWF      FARG_ApplyPaddleState_paddleState+0
	CALL       _ApplyPaddleState+0
;PicPong_Project.c,150 :: 		ApplyPaddleState(PLAYER2_COL, p2Render);
	MOVLW      2
	MOVWF      FARG_ApplyPaddleState_playerCol+0
	MOVF       RenderFrame_p2Render_L0+0, 0
	MOVWF      FARG_ApplyPaddleState_paddleState+0
	CALL       _ApplyPaddleState+0
;PicPong_Project.c,152 :: 		if ((ballX != PLAYER1_COL) && (ballX != PLAYER2_COL)) {
	MOVLW      0
	XORWF      _ballX+1, 0
	BTFSS      STATUS+0, 2
	GOTO       L__RenderFrame116
	MOVLW      7
	XORWF      _ballX+0, 0
L__RenderFrame116:
	BTFSC      STATUS+0, 2
	GOTO       L_RenderFrame10
	MOVLW      0
	XORWF      _ballX+1, 0
	BTFSS      STATUS+0, 2
	GOTO       L__RenderFrame117
	MOVLW      2
	XORWF      _ballX+0, 0
L__RenderFrame117:
	BTFSC      STATUS+0, 2
	GOTO       L_RenderFrame10
L__RenderFrame102:
;PicPong_Project.c,153 :: 		MAX7219_Send((unsigned char)ballX, ballYState);
	MOVF       _ballX+0, 0
	MOVWF      FARG_MAX7219_Send_regAddr+0
	MOVF       _ballYState+0, 0
	MOVWF      FARG_MAX7219_Send_regData+0
	CALL       _MAX7219_Send+0
;PicPong_Project.c,154 :: 		}
L_RenderFrame10:
;PicPong_Project.c,155 :: 		}
L_end_RenderFrame:
	RETURN
; end of _RenderFrame

_InitGame:

;PicPong_Project.c,157 :: 		void InitGame() {
;PicPong_Project.c,158 :: 		p1State = STATE_3;
	MOVLW      60
	MOVWF      _p1State+0
;PicPong_Project.c,159 :: 		p2State = STATE_3;
	MOVLW      60
	MOVWF      _p2State+0
;PicPong_Project.c,160 :: 		ballX = 5;
	MOVLW      5
	MOVWF      _ballX+0
	MOVLW      0
	MOVWF      _ballX+1
;PicPong_Project.c,161 :: 		ballYState = Row4;
	MOVLW      16
	MOVWF      _ballYState+0
;PicPong_Project.c,162 :: 		ballDirX = -1;
	MOVLW      255
	MOVWF      _ballDirX+0
	MOVLW      255
	MOVWF      _ballDirX+1
;PicPong_Project.c,163 :: 		ballDirY = 1;
	MOVLW      1
	MOVWF      _ballDirY+0
	MOVLW      0
	MOVWF      _ballDirY+1
;PicPong_Project.c,164 :: 		isScore = false;
	CLRF       _isScore+0
;PicPong_Project.c,166 :: 		MAX7219_Clear();
	CALL       _MAX7219_Clear+0
;PicPong_Project.c,167 :: 		RenderFrame();
	CALL       _RenderFrame+0
;PicPong_Project.c,168 :: 		}
L_end_InitGame:
	RETURN
; end of _InitGame

_ReadButton0:

;PicPong_Project.c,171 :: 		unsigned char ReadButton0() { return BUTTON_PRESSED(Player1_up_pin); }
	CLRF       R1+0
	BTFSC      RB3_bit+0, BitPos(RB3_bit+0)
	INCF       R1+0, 1
	MOVF       R1+0, 0
	XORLW      1
	MOVLW      1
	BTFSS      STATUS+0, 2
	MOVLW      0
	MOVWF      R0+0
L_end_ReadButton0:
	RETURN
; end of _ReadButton0

_ReadButton1:

;PicPong_Project.c,172 :: 		unsigned char ReadButton1() { return BUTTON_PRESSED(Player1_down_pin); }
	CLRF       R1+0
	BTFSC      RB2_bit+0, BitPos(RB2_bit+0)
	INCF       R1+0, 1
	MOVF       R1+0, 0
	XORLW      1
	MOVLW      1
	BTFSS      STATUS+0, 2
	MOVLW      0
	MOVWF      R0+0
L_end_ReadButton1:
	RETURN
; end of _ReadButton1

_ReadButton2:

;PicPong_Project.c,173 :: 		unsigned char ReadButton2() { return BUTTON_PRESSED(Player2_up_pin); }
	CLRF       R1+0
	BTFSC      RB1_bit+0, BitPos(RB1_bit+0)
	INCF       R1+0, 1
	MOVF       R1+0, 0
	XORLW      1
	MOVLW      1
	BTFSS      STATUS+0, 2
	MOVLW      0
	MOVWF      R0+0
L_end_ReadButton2:
	RETURN
; end of _ReadButton2

_ReadButton3:

;PicPong_Project.c,174 :: 		unsigned char ReadButton3() { return BUTTON_PRESSED(Player2_down_pin); }
	CLRF       R1+0
	BTFSC      RB0_bit+0, BitPos(RB0_bit+0)
	INCF       R1+0, 1
	MOVF       R1+0, 0
	XORLW      1
	MOVLW      1
	BTFSS      STATUS+0, 2
	MOVLW      0
	MOVWF      R0+0
L_end_ReadButton3:
	RETURN
; end of _ReadButton3

_ButtonGoUp:

;PicPong_Project.c,177 :: 		void ButtonGoUp(unsigned char player) {
;PicPong_Project.c,178 :: 		if (player == 1) {
	MOVF       FARG_ButtonGoUp_player+0, 0
	XORLW      1
	BTFSS      STATUS+0, 2
	GOTO       L_ButtonGoUp11
;PicPong_Project.c,179 :: 		switch (p1State) {
	GOTO       L_ButtonGoUp12
;PicPong_Project.c,180 :: 		case STATE_1: p1State = STATE_2; break;
L_ButtonGoUp14:
	MOVLW      30
	MOVWF      _p1State+0
	GOTO       L_ButtonGoUp13
;PicPong_Project.c,181 :: 		case STATE_2: p1State = STATE_3; break;
L_ButtonGoUp15:
	MOVLW      60
	MOVWF      _p1State+0
	GOTO       L_ButtonGoUp13
;PicPong_Project.c,182 :: 		case STATE_3: p1State = STATE_4; break;
L_ButtonGoUp16:
	MOVLW      120
	MOVWF      _p1State+0
	GOTO       L_ButtonGoUp13
;PicPong_Project.c,183 :: 		case STATE_4: p1State = STATE_5; break;
L_ButtonGoUp17:
	MOVLW      240
	MOVWF      _p1State+0
	GOTO       L_ButtonGoUp13
;PicPong_Project.c,184 :: 		case STATE_5: p1State = STATE_5; break;
L_ButtonGoUp18:
	MOVLW      240
	MOVWF      _p1State+0
	GOTO       L_ButtonGoUp13
;PicPong_Project.c,185 :: 		default:      p1State = STATE_3; break;
L_ButtonGoUp19:
	MOVLW      60
	MOVWF      _p1State+0
	GOTO       L_ButtonGoUp13
;PicPong_Project.c,186 :: 		}
L_ButtonGoUp12:
	MOVF       _p1State+0, 0
	XORLW      15
	BTFSC      STATUS+0, 2
	GOTO       L_ButtonGoUp14
	MOVF       _p1State+0, 0
	XORLW      30
	BTFSC      STATUS+0, 2
	GOTO       L_ButtonGoUp15
	MOVF       _p1State+0, 0
	XORLW      60
	BTFSC      STATUS+0, 2
	GOTO       L_ButtonGoUp16
	MOVF       _p1State+0, 0
	XORLW      120
	BTFSC      STATUS+0, 2
	GOTO       L_ButtonGoUp17
	MOVF       _p1State+0, 0
	XORLW      240
	BTFSC      STATUS+0, 2
	GOTO       L_ButtonGoUp18
	GOTO       L_ButtonGoUp19
L_ButtonGoUp13:
;PicPong_Project.c,187 :: 		} else {
	GOTO       L_ButtonGoUp20
L_ButtonGoUp11:
;PicPong_Project.c,188 :: 		switch (p2State) {
	GOTO       L_ButtonGoUp21
;PicPong_Project.c,189 :: 		case STATE_1: p2State = STATE_2; break;
L_ButtonGoUp23:
	MOVLW      30
	MOVWF      _p2State+0
	GOTO       L_ButtonGoUp22
;PicPong_Project.c,190 :: 		case STATE_2: p2State = STATE_3; break;
L_ButtonGoUp24:
	MOVLW      60
	MOVWF      _p2State+0
	GOTO       L_ButtonGoUp22
;PicPong_Project.c,191 :: 		case STATE_3: p2State = STATE_4; break;
L_ButtonGoUp25:
	MOVLW      120
	MOVWF      _p2State+0
	GOTO       L_ButtonGoUp22
;PicPong_Project.c,192 :: 		case STATE_4: p2State = STATE_5; break;
L_ButtonGoUp26:
	MOVLW      240
	MOVWF      _p2State+0
	GOTO       L_ButtonGoUp22
;PicPong_Project.c,193 :: 		case STATE_5: p2State = STATE_5; break;
L_ButtonGoUp27:
	MOVLW      240
	MOVWF      _p2State+0
	GOTO       L_ButtonGoUp22
;PicPong_Project.c,194 :: 		default:      p2State = STATE_3; break;
L_ButtonGoUp28:
	MOVLW      60
	MOVWF      _p2State+0
	GOTO       L_ButtonGoUp22
;PicPong_Project.c,195 :: 		}
L_ButtonGoUp21:
	MOVF       _p2State+0, 0
	XORLW      15
	BTFSC      STATUS+0, 2
	GOTO       L_ButtonGoUp23
	MOVF       _p2State+0, 0
	XORLW      30
	BTFSC      STATUS+0, 2
	GOTO       L_ButtonGoUp24
	MOVF       _p2State+0, 0
	XORLW      60
	BTFSC      STATUS+0, 2
	GOTO       L_ButtonGoUp25
	MOVF       _p2State+0, 0
	XORLW      120
	BTFSC      STATUS+0, 2
	GOTO       L_ButtonGoUp26
	MOVF       _p2State+0, 0
	XORLW      240
	BTFSC      STATUS+0, 2
	GOTO       L_ButtonGoUp27
	GOTO       L_ButtonGoUp28
L_ButtonGoUp22:
;PicPong_Project.c,196 :: 		}
L_ButtonGoUp20:
;PicPong_Project.c,197 :: 		}
L_end_ButtonGoUp:
	RETURN
; end of _ButtonGoUp

_ButtonGoDown:

;PicPong_Project.c,199 :: 		void ButtonGoDown(unsigned char player) {
;PicPong_Project.c,200 :: 		if (player == 1) {
	MOVF       FARG_ButtonGoDown_player+0, 0
	XORLW      1
	BTFSS      STATUS+0, 2
	GOTO       L_ButtonGoDown29
;PicPong_Project.c,201 :: 		switch (p1State) {
	GOTO       L_ButtonGoDown30
;PicPong_Project.c,202 :: 		case STATE_1: p1State = STATE_1; break;
L_ButtonGoDown32:
	MOVLW      15
	MOVWF      _p1State+0
	GOTO       L_ButtonGoDown31
;PicPong_Project.c,203 :: 		case STATE_2: p1State = STATE_1; break;
L_ButtonGoDown33:
	MOVLW      15
	MOVWF      _p1State+0
	GOTO       L_ButtonGoDown31
;PicPong_Project.c,204 :: 		case STATE_3: p1State = STATE_2; break;
L_ButtonGoDown34:
	MOVLW      30
	MOVWF      _p1State+0
	GOTO       L_ButtonGoDown31
;PicPong_Project.c,205 :: 		case STATE_4: p1State = STATE_3; break;
L_ButtonGoDown35:
	MOVLW      60
	MOVWF      _p1State+0
	GOTO       L_ButtonGoDown31
;PicPong_Project.c,206 :: 		case STATE_5: p1State = STATE_4; break;
L_ButtonGoDown36:
	MOVLW      120
	MOVWF      _p1State+0
	GOTO       L_ButtonGoDown31
;PicPong_Project.c,207 :: 		default:      p1State = STATE_3; break;
L_ButtonGoDown37:
	MOVLW      60
	MOVWF      _p1State+0
	GOTO       L_ButtonGoDown31
;PicPong_Project.c,208 :: 		}
L_ButtonGoDown30:
	MOVF       _p1State+0, 0
	XORLW      15
	BTFSC      STATUS+0, 2
	GOTO       L_ButtonGoDown32
	MOVF       _p1State+0, 0
	XORLW      30
	BTFSC      STATUS+0, 2
	GOTO       L_ButtonGoDown33
	MOVF       _p1State+0, 0
	XORLW      60
	BTFSC      STATUS+0, 2
	GOTO       L_ButtonGoDown34
	MOVF       _p1State+0, 0
	XORLW      120
	BTFSC      STATUS+0, 2
	GOTO       L_ButtonGoDown35
	MOVF       _p1State+0, 0
	XORLW      240
	BTFSC      STATUS+0, 2
	GOTO       L_ButtonGoDown36
	GOTO       L_ButtonGoDown37
L_ButtonGoDown31:
;PicPong_Project.c,209 :: 		} else {
	GOTO       L_ButtonGoDown38
L_ButtonGoDown29:
;PicPong_Project.c,210 :: 		switch (p2State) {
	GOTO       L_ButtonGoDown39
;PicPong_Project.c,211 :: 		case STATE_1: p2State = STATE_1; break;
L_ButtonGoDown41:
	MOVLW      15
	MOVWF      _p2State+0
	GOTO       L_ButtonGoDown40
;PicPong_Project.c,212 :: 		case STATE_2: p2State = STATE_1; break;
L_ButtonGoDown42:
	MOVLW      15
	MOVWF      _p2State+0
	GOTO       L_ButtonGoDown40
;PicPong_Project.c,213 :: 		case STATE_3: p2State = STATE_2; break;
L_ButtonGoDown43:
	MOVLW      30
	MOVWF      _p2State+0
	GOTO       L_ButtonGoDown40
;PicPong_Project.c,214 :: 		case STATE_4: p2State = STATE_3; break;
L_ButtonGoDown44:
	MOVLW      60
	MOVWF      _p2State+0
	GOTO       L_ButtonGoDown40
;PicPong_Project.c,215 :: 		case STATE_5: p2State = STATE_4; break;
L_ButtonGoDown45:
	MOVLW      120
	MOVWF      _p2State+0
	GOTO       L_ButtonGoDown40
;PicPong_Project.c,216 :: 		default:      p2State = STATE_3; break;
L_ButtonGoDown46:
	MOVLW      60
	MOVWF      _p2State+0
	GOTO       L_ButtonGoDown40
;PicPong_Project.c,217 :: 		}
L_ButtonGoDown39:
	MOVF       _p2State+0, 0
	XORLW      15
	BTFSC      STATUS+0, 2
	GOTO       L_ButtonGoDown41
	MOVF       _p2State+0, 0
	XORLW      30
	BTFSC      STATUS+0, 2
	GOTO       L_ButtonGoDown42
	MOVF       _p2State+0, 0
	XORLW      60
	BTFSC      STATUS+0, 2
	GOTO       L_ButtonGoDown43
	MOVF       _p2State+0, 0
	XORLW      120
	BTFSC      STATUS+0, 2
	GOTO       L_ButtonGoDown44
	MOVF       _p2State+0, 0
	XORLW      240
	BTFSC      STATUS+0, 2
	GOTO       L_ButtonGoDown45
	GOTO       L_ButtonGoDown46
L_ButtonGoDown40:
;PicPong_Project.c,218 :: 		}
L_ButtonGoDown38:
;PicPong_Project.c,219 :: 		}
L_end_ButtonGoDown:
	RETURN
; end of _ButtonGoDown

_UpdateBallPosition:
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
;PicPong_Project.c,263 :: 		void main() {
;PicPong_Project.c,267 :: 		TRISB = 0xFF;
	MOVLW      255
	MOVWF      TRISB+0
;PicPong_Project.c,268 :: 		TRISC = 0x00;
	CLRF       TRISC+0
;PicPong_Project.c,269 :: 		PORTB = 0x00;
	CLRF       PORTB+0
;PicPong_Project.c,270 :: 		PORTC = 0x00;
	CLRF       PORTC+0
;PicPong_Project.c,272 :: 		OPTION_REG |= 0x80;   // disable PORTB pull-ups
	BSF        OPTION_REG+0, 7
;PicPong_Project.c,274 :: 		MAX7219_Init();
	CALL       _MAX7219_Init+0
;PicPong_Project.c,275 :: 		MAX7219_Config();
	CALL       _MAX7219_Config+0
;PicPong_Project.c,277 :: 		while (1) {
L_main82:
;PicPong_Project.c,278 :: 		InitGame();
	CALL       _InitGame+0
;PicPong_Project.c,280 :: 		while (!isScore) {
L_main84:
	MOVF       _isScore+0, 0
	BTFSS      STATUS+0, 2
	GOTO       L_main85
;PicPong_Project.c,281 :: 		elapsed = 0;
	CLRF       main_elapsed_L0+0
	CLRF       main_elapsed_L0+1
;PicPong_Project.c,282 :: 		UpdateBallPosition();
	CALL       _UpdateBallPosition+0
;PicPong_Project.c,284 :: 		while (elapsed < FRAME_DELAY_MS) {
L_main86:
	MOVLW      3
	SUBWF      main_elapsed_L0+1, 0
	BTFSS      STATUS+0, 2
	GOTO       L__main137
	MOVLW      232
	SUBWF      main_elapsed_L0+0, 0
L__main137:
	BTFSC      STATUS+0, 0
	GOTO       L_main87
;PicPong_Project.c,285 :: 		b0 = ReadButton0();
	CALL       _ReadButton0+0
	MOVF       R0+0, 0
	MOVWF      main_b0_L0+0
;PicPong_Project.c,286 :: 		b1 = ReadButton1();
	CALL       _ReadButton1+0
	MOVF       R0+0, 0
	MOVWF      main_b1_L0+0
;PicPong_Project.c,287 :: 		b2 = ReadButton2();
	CALL       _ReadButton2+0
	MOVF       R0+0, 0
	MOVWF      main_b2_L0+0
;PicPong_Project.c,288 :: 		b3 = ReadButton3();
	CALL       _ReadButton3+0
	MOVF       R0+0, 0
	MOVWF      main_b3_L0+0
;PicPong_Project.c,290 :: 		if (b0 && !prevB0) {
	MOVF       main_b0_L0+0, 0
	BTFSC      STATUS+0, 2
	GOTO       L_main90
	MOVF       _prevB0+0, 0
	BTFSS      STATUS+0, 2
	GOTO       L_main90
L__main107:
;PicPong_Project.c,291 :: 		ButtonGoUp(1);
	MOVLW      1
	MOVWF      FARG_ButtonGoUp_player+0
	CALL       _ButtonGoUp+0
;PicPong_Project.c,292 :: 		RenderFrame();
	CALL       _RenderFrame+0
;PicPong_Project.c,293 :: 		}
L_main90:
;PicPong_Project.c,294 :: 		if (b1 && !prevB1) {
	MOVF       main_b1_L0+0, 0
	BTFSC      STATUS+0, 2
	GOTO       L_main93
	MOVF       _prevB1+0, 0
	BTFSS      STATUS+0, 2
	GOTO       L_main93
L__main106:
;PicPong_Project.c,295 :: 		ButtonGoDown(1);
	MOVLW      1
	MOVWF      FARG_ButtonGoDown_player+0
	CALL       _ButtonGoDown+0
;PicPong_Project.c,296 :: 		RenderFrame();
	CALL       _RenderFrame+0
;PicPong_Project.c,297 :: 		}
L_main93:
;PicPong_Project.c,298 :: 		if (b2 && !prevB2) {
	MOVF       main_b2_L0+0, 0
	BTFSC      STATUS+0, 2
	GOTO       L_main96
	MOVF       _prevB2+0, 0
	BTFSS      STATUS+0, 2
	GOTO       L_main96
L__main105:
;PicPong_Project.c,299 :: 		ButtonGoUp(2);
	MOVLW      2
	MOVWF      FARG_ButtonGoUp_player+0
	CALL       _ButtonGoUp+0
;PicPong_Project.c,300 :: 		RenderFrame();
	CALL       _RenderFrame+0
;PicPong_Project.c,301 :: 		}
L_main96:
;PicPong_Project.c,302 :: 		if (b3 && !prevB3) {
	MOVF       main_b3_L0+0, 0
	BTFSC      STATUS+0, 2
	GOTO       L_main99
	MOVF       _prevB3+0, 0
	BTFSS      STATUS+0, 2
	GOTO       L_main99
L__main104:
;PicPong_Project.c,303 :: 		ButtonGoDown(2);
	MOVLW      2
	MOVWF      FARG_ButtonGoDown_player+0
	CALL       _ButtonGoDown+0
;PicPong_Project.c,304 :: 		RenderFrame();
	CALL       _RenderFrame+0
;PicPong_Project.c,305 :: 		}
L_main99:
;PicPong_Project.c,307 :: 		prevB0 = b0;
	MOVF       main_b0_L0+0, 0
	MOVWF      _prevB0+0
;PicPong_Project.c,308 :: 		prevB1 = b1;
	MOVF       main_b1_L0+0, 0
	MOVWF      _prevB1+0
;PicPong_Project.c,309 :: 		prevB2 = b2;
	MOVF       main_b2_L0+0, 0
	MOVWF      _prevB2+0
;PicPong_Project.c,310 :: 		prevB3 = b3;
	MOVF       main_b3_L0+0, 0
	MOVWF      _prevB3+0
;PicPong_Project.c,312 :: 		Delay_ms(DEBOUNCE_DELAY_MS);
	MOVLW      21
	MOVWF      R12+0
	MOVLW      198
	MOVWF      R13+0
L_main100:
	DECFSZ     R13+0, 1
	GOTO       L_main100
	DECFSZ     R12+0, 1
	GOTO       L_main100
	NOP
;PicPong_Project.c,313 :: 		elapsed += DEBOUNCE_DELAY_MS;
	MOVLW      8
	ADDWF      main_elapsed_L0+0, 1
	BTFSC      STATUS+0, 0
	INCF       main_elapsed_L0+1, 1
;PicPong_Project.c,314 :: 		}
	GOTO       L_main86
L_main87:
;PicPong_Project.c,315 :: 		}
	GOTO       L_main84
L_main85:
;PicPong_Project.c,317 :: 		Delay_ms(250);
	MOVLW      3
	MOVWF      R11+0
	MOVLW      138
	MOVWF      R12+0
	MOVLW      85
	MOVWF      R13+0
L_main101:
	DECFSZ     R13+0, 1
	GOTO       L_main101
	DECFSZ     R12+0, 1
	GOTO       L_main101
	DECFSZ     R11+0, 1
	GOTO       L_main101
	NOP
	NOP
;PicPong_Project.c,318 :: 		}
	GOTO       L_main82
;PicPong_Project.c,319 :: 		}
L_end_main:
	GOTO       $+0
; end of _main
